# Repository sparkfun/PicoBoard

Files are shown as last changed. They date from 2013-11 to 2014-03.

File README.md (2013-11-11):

Picoboard
=========

[PicoBoard 
*PicoBoard (WIG-10311)*](https://www.sparkfun.com/products/10311)

The PicoBoard allows you to interface hardware sensors with the Scratch programming language.

Repository Contents
-------------------
* **/hardware** - All Eagle design files (.brd, .sch, .STL)
* **/firmware** - PicoBoard source code for an ATmega328.

License Information
-------------------
The contents released under [Creative Commons Share-alike 3.0](http://creativecommons.org/licenses/by-sa/3.0/).

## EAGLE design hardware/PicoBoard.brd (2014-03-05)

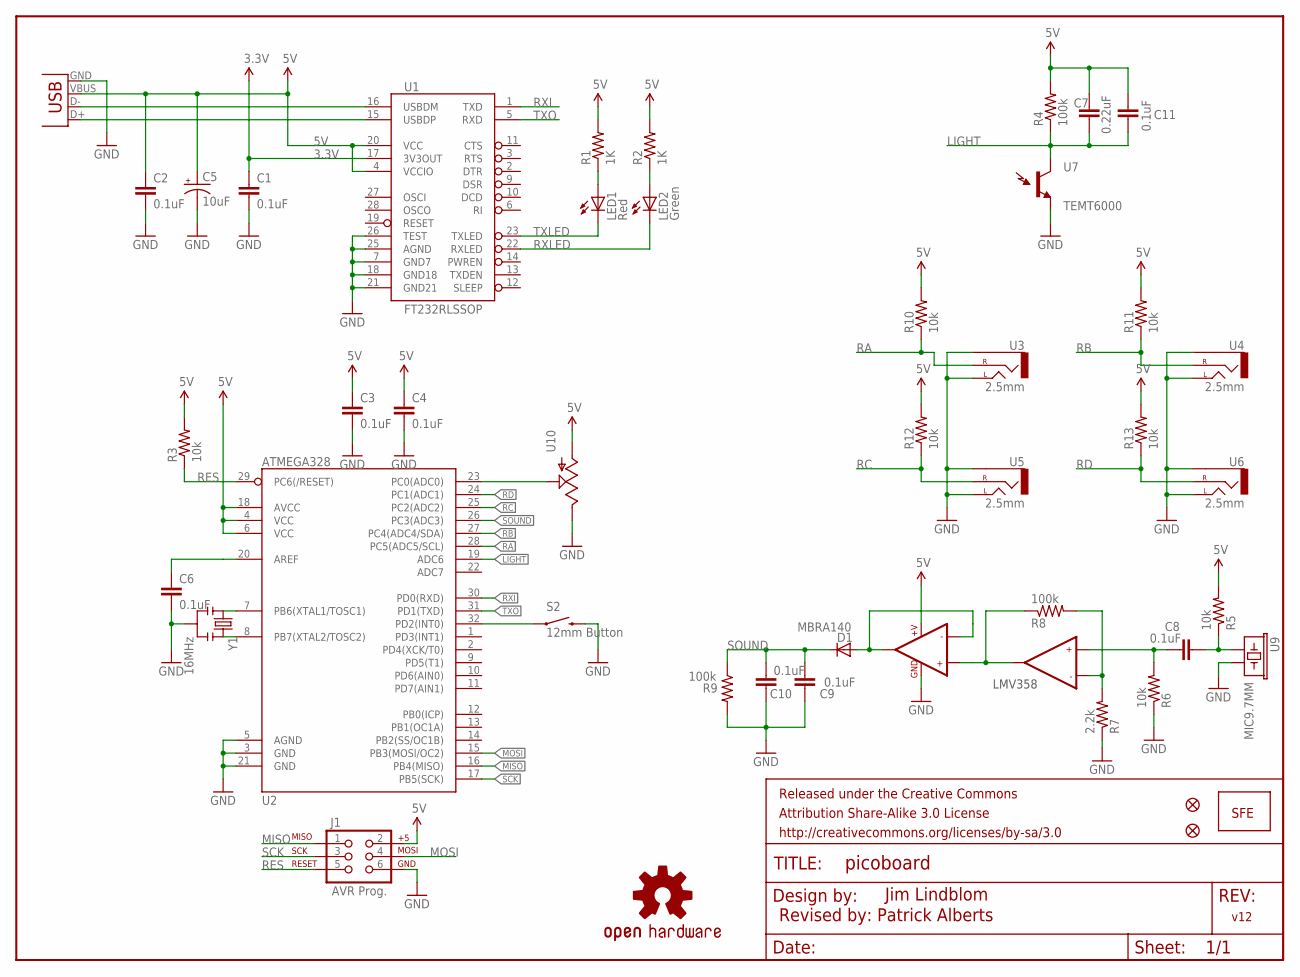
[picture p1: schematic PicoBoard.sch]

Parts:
C1, C2, C3, C4, C6, C8, C9, C10, C11: 0.1uF; 0603-CAP
C5: 10uF; EIA3216
C7: 0.22uF; 0603-CAP
D1: MBRA140; SMA-DIODE
FID1, FID2: FIDUCIAL1X2; FIDUCIAL-1X2
FRAME1: FRAME-LETTER; CREATIVE_COMMONS
J1: AVR Prog.; 2X3
JP1: LOGO-SFENEW; SFE-NEW-WEBLOGO
LED1: Red; LED-0603
LED2: Green; LED-0603
LOGO1: OSHW-LOGOL; OSHW-LOGO-L
R1, R2: 1K; 0603-RES
R3, R5, R6, R10, R11, R12, R13: 10k; 0603-RES
R4, R8, R9: 100k; 0603-RES
R7: 2.2k; 0603-RES
S2: 12mm Button; TACTILE-SMD-12MM
U1: FT232RLSSOP; SSOP28DB
U2: ATMEGA328; TQFP32-08
U3, U4, U5, U6: 2.5mm; STEREOJACK2.5MM
U7: TEMT6000; TEMT6000-SEN
U8: LMV358; SO08
U9: MIC9.7MM; MIC-9.7MM
U10: SLIDER60MM; SLIDER
X1: USBSMD; USB-MINIB
Y1: 16MHz; RESONATOR-SMD

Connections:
3.3V: C1.1, U1.17 (3V3OUT)
5V: C2.1, C3.1, C4.1, C5.A (+), C7.1, C11.1, J1.2, R1.2, R2.2, R3.2, R4.2, R5.2, R10.2, R11.2, R12.2, R13.2, U1.4 (VCCIO), U1.20 (VCC), U2.4 (VCC), U2.6 (VCC), U2.18 (AVCC), U8.8 (+V), U10.3 (A), X1.VBUS
GND: C1.2, C2.2, C3.2, C4.2, C5.C (-), C6.2, C9.1, C10.1, J1.6, R6.1, R7.1, R9.2, S2.3 (2), U1.7 (GND7), U1.18 (GND18), U1.21 (GND21), U1.25 (AGND), U1.26 (TEST), U2.3 (GND), U2.5 (AGND), U2.21 (GND), U3.1 (LEFT), U3.5 (SLEEVE), U4.1 (LEFT), U4.5 (SLEEVE), U5.1 (LEFT), U5.5 (SLEEVE), U6.1 (LEFT), U6.5 (SLEEVE), U7.EMITTER (E1), U8.4 (GND), U9.2, U10.1 (E), X1.GND, Y1.2
LIGHT: C7.2, C11.2, R4.1, U2.19 (ADC6), U7.COLLECTOR (C1)
MISO: J1.1, U2.16 (PB4(MISO))
MOSI: J1.4, U2.15 (PB3(MOSI/OC2))
unnamed: LED1.A, R1.1
unnamed: LED2.A, R2.1
unnamed: R7.2, R8.2, U8.6 (-IN2)
unnamed: U2.7 (PB6(XTAL1/TOSC1)), Y1.1
unnamed: U2.8 (PB7(XTAL2/TOSC2)), Y1.3
unnamed: C6.1, U2.20 (AREF)
unnamed: S2.1, U2.32 (PD2(INT0))
unnamed: C8.1, R5.1, U9.1
unnamed: U2.23 (PC0(ADC0)), U10.2A (S)
unnamed: C8.2, R6.2, U8.5 (+IN2)
unnamed: D1.A, U8.1 (OUT1), U8.2 (-IN1)
unnamed: R8.1, U8.3 (+IN1), U8.7 (OUT2)
RA: R10.1, U2.28 (PC5(ADC5/SCL)), U3.4 (RIGHT)
RB: R11.1, U2.27 (PC4(ADC4/SDA)), U4.4 (RIGHT)
RC: R12.1, U2.25 (PC2(ADC2)), U5.4 (RIGHT)
RD: R13.1, U2.24 (PC1(ADC1)), U6.4 (RIGHT)
RES: J1.5, R3.1, U2.29 (PC6(/RESET))
RXI: U1.1 (TXD), U2.30 (PD0(RXD))
RXLED: LED2.C, U1.22 (RXLED)
SCK: J1.3, U2.17 (PB5(SCK))
SOUND: C9.2, C10.2, D1.C, R9.1, U2.26 (PC3(ADC3))
TXLED: LED1.C, U1.23 (TXLED)
TXO: U1.5 (RXD), U2.31 (PD1(TXD))
USB_D+: U1.15 (USBDP), X1.D+
USB_D-: U1.16 (USBDM), X1.D-

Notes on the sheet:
LMV358
Jim Lindblom
Revised by: Patrick Alberts
v12

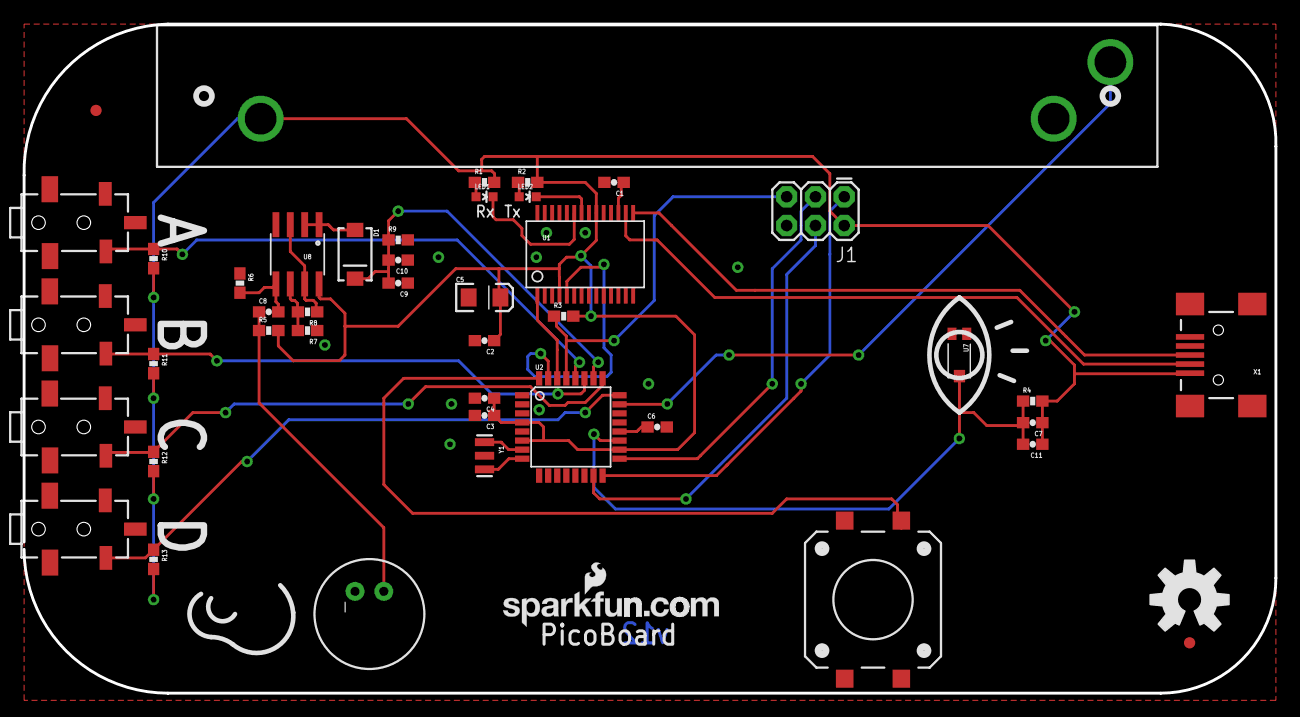
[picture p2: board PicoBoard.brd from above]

Board: 2 copper layers, 110.5 x 59.1 mm, 46 parts (0 on the bottom side), 31 nets.

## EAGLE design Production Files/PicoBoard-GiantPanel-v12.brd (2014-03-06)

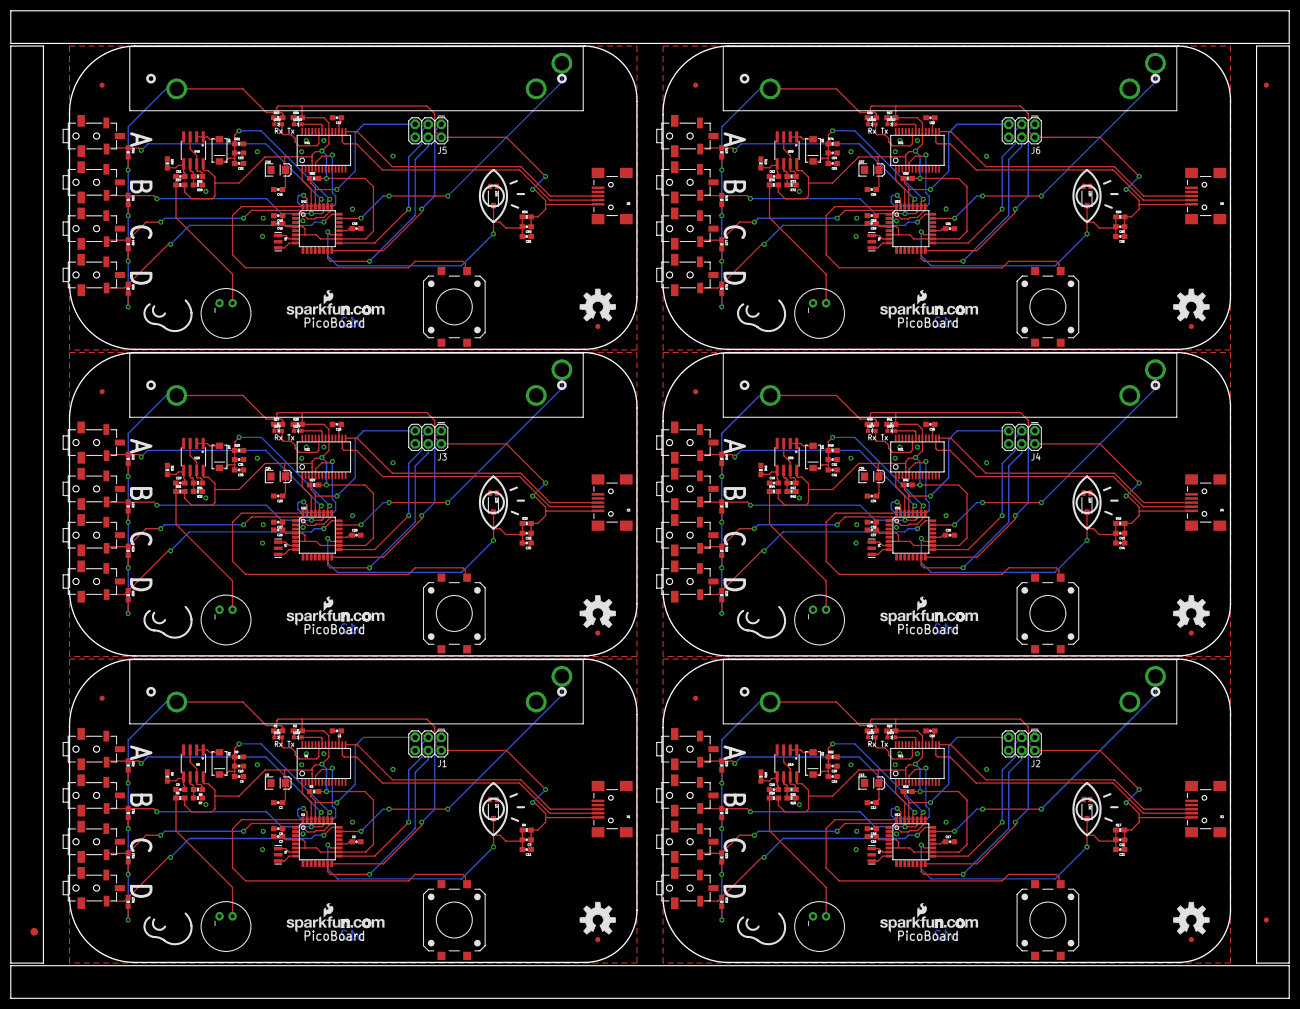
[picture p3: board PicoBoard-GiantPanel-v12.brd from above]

Board: 2 copper layers, 248.9 x 192.3 mm, 273 parts (0 on the bottom side), 186 nets.

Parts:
C1, C2, C3, C4, C6, C8, C9, C10, C11, C12, C14, C15, C16, C17, C18, C19, C20, C22, C23, C25, C26, C27, C28, C29, C30, C31, C33, C34, C36, C37, C38, C39, C40, C41, C42, C44, C45, C47, C48, C49, C50, C51, C52, C53, C55, C56, C58, C59, C60, C61, C62, C63, C64, C66: 0.1uF; 0603-CAP
C5, C13, C24, C35, C46, C57: 10uF; EIA3216
C7, C21, C32, C43, C54, C65: 0.22uF; 0603-CAP
D1, D2, D3, D4, D5, D6: MBRA140; SMA-DIODE
E$1: FIDUCIAL-1.5X3
E$2, E$4: FIDUCIAL-1X2
FID1, FID2, FID3, FID4, FID5, FID6, FID7, FID8, FID9, FID10, FID11, FID12: FIDUCIAL1X2; FIDUCIAL-1X2
J1, J2, J3, J4, J5, J6: AVR Prog.; 2X3
JP1, JP2, JP3, JP4, JP5, JP6: LOGO-SFENEW; SFE-NEW-WEBLOGO
LED1, LED3, LED5, LED7, LED9, LED11: Red; LED-0603
LED2, LED4, LED6, LED8, LED10, LED12: Green; LED-0603
LOGO1, LOGO2, LOGO3, LOGO4, LOGO5, LOGO6: OSHW-LOGOL; OSHW-LOGO-L
R1, R2, R14, R15, R27, R28, R40, R41, R53, R54, R66, R67: 1K; 0603-RES
R3, R5, R6, R10, R11, R12, R13, R16, R18, R19, R23, R24, R25, R26, R29, R31, R32, R36, R37, R38, R39, R42, R44, R45, R49, R50, R51, R52, R55, R57, R58, R62, R63, R64, R65, R68, R70, R71, R75, R76, R77, R78: 10k; 0603-RES
R4, R8, R9, R17, R21, R22, R30, R34, R35, R43, R47, R48, R56, R60, R61, R69, R73, R74: 100k; 0603-RES
R7, R20, R33, R46, R59, R72: 2.2k; 0603-RES
S1, S2, S3, S4, S5, S6: 12mm Button; TACTILE-SMD-12MM
U1, U11, U21, U31, U41, U51: FT232RLSSOP; SSOP28DB
U2, U12, U22, U32, U42, U52: ATMEGA328; TQFP32-08
U3, U4, U5, U6, U13, U14, U15, U16, U23, U24, U25, U26, U33, U34, U35, U36, U43, U44, U45, U46, U53, U54, U55, U56: 2.5mm; STEREOJACK2.5MM
U7, U17, U27, U37, U47, U57: TEMT6000; TEMT6000-SEN
U8, U19, U29, U39, U49, U59: LMV358; SO08
U9, U18, U28, U38, U48, U58: MIC9.7MM; MIC-9.7MM
U10, U20, U30, U40, U50, U60: SLIDER
X1, X2, X3, X4, X5, X6: USBSMD; USB-MINIB
Y1, Y2, Y3, Y4, Y5, Y6: 16MHz; RESONATOR-SMD

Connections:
3.3V: C1.1, U1.17
3.3V1: C14.1, U11.17
3.3V2: C25.1, U21.17
3.3V3: C36.1, U31.17
3.3V4: C47.1, U41.17
3.3V5: C58.1, U51.17
5V: C2.1, C3.1, C4.1, C5.A, C7.1, C11.1, J1.2, R1.2, R2.2, R3.2, R4.2, R5.2, R10.2, R11.2, R12.2, R13.2, U1.4, U1.20, U2.4, U2.6, U2.18, U8.8, U10.3, X1.VBUS
5V1: C12.1, C13.A, C15.1, C16.1, C21.1, C22.1, J2.2, R14.2, R15.2, R16.2, R17.2, R18.2, R23.2, R24.2, R25.2, R26.2, U11.4, U11.20, U12.4, U12.6, U12.18, U19.8, U20.3, X2.VBUS
5V2: C23.1, C24.A, C26.1, C27.1, C32.1, C33.1, J3.2, R27.2, R28.2, R29.2, R30.2, R31.2, R36.2, R37.2, R38.2, R39.2, U21.4, U21.20, U22.4, U22.6, U22.18, U29.8, U30.3, X3.VBUS
5V3: C34.1, C35.A, C37.1, C38.1, C43.1, C44.1, J4.2, R40.2, R41.2, R42.2, R43.2, R44.2, R49.2, R50.2, R51.2, R52.2, U31.4, U31.20, U32.4, U32.6, U32.18, U39.8, U40.3, X4.VBUS
5V4: C45.1, C46.A, C48.1, C49.1, C54.1, C55.1, J5.2, R53.2, R54.2, R55.2, R56.2, R57.2, R62.2, R63.2, R64.2, R65.2, U41.4, U41.20, U42.4, U42.6, U42.18, U49.8, U50.3, X5.VBUS
5V5: C56.1, C57.A, C59.1, C60.1, C65.1, C66.1, J6.2, R66.2, R67.2, R68.2, R69.2, R70.2, R75.2, R76.2, R77.2, R78.2, U51.4, U51.20, U52.4, U52.6, U52.18, U59.8, U60.3, X6.VBUS
GND: C1.2, C2.2, C3.2, C4.2, C5.C, C6.2, C9.1, C10.1, J1.6, R6.1, R7.1, R9.2, S2.3, U1.7, U1.18, U1.21, U1.25, U1.26, U2.3, U2.5, U2.21, U3.1, U3.5, U4.1, U4.5, U5.1, U5.5, U6.1, U6.5, U7.EMITTER, U8.4, U9.2, U10.1, X1.GND, Y1.2
GND1: C12.2, C13.C, C14.2, C15.2, C16.2, C17.2, C19.1, C20.1, J2.6, R19.1, R20.1, R22.2, S1.3, U11.7, U11.18, U11.21, U11.25, U11.26, U12.3, U12.5, U12.21, U13.1, U13.5, U14.1, U14.5, U15.1, U15.5, U16.1, U16.5, U17.EMITTER, U18.2, U19.4, U20.1, X2.GND, Y2.2
GND2: C23.2, C24.C, C25.2, C26.2, C27.2, C28.2, C30.1, C31.1, J3.6, R32.1, R33.1, R35.2, S3.3, U21.7, U21.18, U21.21, U21.25, U21.26, U22.3, U22.5, U22.21, U23.1, U23.5, U24.1, U24.5, U25.1, U25.5, U26.1, U26.5, U27.EMITTER, U28.2, U29.4, U30.1, X3.GND, Y3.2
GND3: C34.2, C35.C, C36.2, C37.2, C38.2, C39.2, C41.1, C42.1, J4.6, R45.1, R46.1, R48.2, S4.3, U31.7, U31.18, U31.21, U31.25, U31.26, U32.3, U32.5, U32.21, U33.1, U33.5, U34.1, U34.5, U35.1, U35.5, U36.1, U36.5, U37.EMITTER, U38.2, U39.4, U40.1, X4.GND, Y4.2
GND4: C45.2, C46.C, C47.2, C48.2, C49.2, C50.2, C52.1, C53.1, J5.6, R58.1, R59.1, R61.2, S5.3, U41.7, U41.18, U41.21, U41.25, U41.26, U42.3, U42.5, U42.21, U43.1, U43.5, U44.1, U44.5, U45.1, U45.5, U46.1, U46.5, U47.EMITTER, U48.2, U49.4, U50.1, X5.GND, Y5.2
GND5: C56.2, C57.C, C58.2, C59.2, C60.2, C61.2, C63.1, C64.1, J6.6, R71.1, R72.1, R74.2, S6.3, U51.7, U51.18, U51.21, U51.25, U51.26, U52.3, U52.5, U52.21, U53.1, U53.5, U54.1, U54.5, U55.1, U55.5, U56.1, U56.5, U57.EMITTER, U58.2, U59.4, U60.1, X6.GND, Y6.2
LIGHT: C7.2, C11.2, R4.1, U2.19, U7.COLLECTOR
LIGHT1: C21.2, C22.2, R17.1, U12.19, U17.COLLECTOR
LIGHT2: C32.2, C33.2, R30.1, U22.19, U27.COLLECTOR
LIGHT3: C43.2, C44.2, R43.1, U32.19, U37.COLLECTOR
LIGHT4: C54.2, C55.2, R56.1, U42.19, U47.COLLECTOR
LIGHT5: C65.2, C66.2, R69.1, U52.19, U57.COLLECTOR
MISO: J1.1, U2.16
MISO1: J2.1, U12.16
MISO2: J3.1, U22.16
MISO3: J4.1, U32.16
MISO4: J5.1, U42.16
MISO5: J6.1, U52.16
MOSI: J1.4, U2.15
MOSI1: J2.4, U12.15
MOSI2: J3.4, U22.15
MOSI3: J4.4, U32.15
MOSI4: J5.4, U42.15
MOSI5: J6.4, U52.15
unnamed: LED1.A, R1.1
unnamed: LED2.A, R2.1
unnamed: R7.2, R8.2, U8.6
unnamed: LED3.A, R14.1
unnamed: U2.7, Y1.1
unnamed: U2.8, Y1.3
unnamed: C6.1, U2.20
unnamed: S2.1, U2.32
unnamed: C8.1, R5.1, U9.1
unnamed: U2.23, U10.2A
unnamed: C8.2, R6.2, U8.5
unnamed: LED4.A, R15.1
unnamed: D1.A, U8.1, U8.2
unnamed: U12.7, Y2.1
unnamed: U12.8, Y2.3
unnamed: R8.1, U8.3, U8.7
unnamed: C17.1, U12.20
unnamed: S1.1, U12.32
unnamed: C18.1, R18.1, U18.1
unnamed: C18.2, R19.2, U19.5
unnamed: R20.2, R21.2, U19.6
unnamed: D2.A, U19.1, U19.2
unnamed: R21.1, U19.3, U19.7
unnamed: U12.23, U20.2A
unnamed: LED5.A, R27.1
unnamed: LED6.A, R28.1
unnamed: U22.7, Y3.1
unnamed: U22.8, Y3.3
unnamed: C28.1, U22.20
unnamed: S3.1, U22.32
unnamed: C29.1, R31.1, U28.1
unnamed: C29.2, R32.2, U29.5
unnamed: R33.2, R34.2, U29.6
unnamed: D3.A, U29.1, U29.2
unnamed: R34.1, U29.3, U29.7
unnamed: U22.23, U30.2A
unnamed: LED7.A, R40.1
unnamed: LED8.A, R41.1
unnamed: U32.7, Y4.1
unnamed: U32.8, Y4.3
unnamed: C39.1, U32.20
unnamed: S4.1, U32.32
unnamed: C40.1, R44.1, U38.1
unnamed: C40.2, R45.2, U39.5
unnamed: R46.2, R47.2, U39.6
unnamed: D4.A, U39.1, U39.2
unnamed: R47.1, U39.3, U39.7
unnamed: U32.23, U40.2A
unnamed: LED9.A, R53.1
unnamed: LED10.A, R54.1
unnamed: U42.7, Y5.1
unnamed: U42.8, Y5.3
unnamed: C50.1, U42.20
unnamed: S5.1, U42.32
unnamed: C51.1, R57.1, U48.1
unnamed: C51.2, R58.2, U49.5
unnamed: R59.2, R60.2, U49.6
unnamed: D5.A, U49.1, U49.2
unnamed: R60.1, U49.3, U49.7
unnamed: U42.23, U50.2A
unnamed: LED11.A, R66.1
unnamed: LED12.A, R67.1
unnamed: U52.7, Y6.1
unnamed: U52.8, Y6.3
unnamed: C61.1, U52.20
unnamed: S6.1, U52.32
unnamed: C62.1, R70.1, U58.1
unnamed: C62.2, R71.2, U59.5
unnamed: R72.2, R73.2, U59.6
unnamed: D6.A, U59.1, U59.2
unnamed: R73.1, U59.3, U59.7
unnamed: U52.23, U60.2A
RA: R10.1, U2.28, U3.4
RA1: R23.1, U12.28, U13.4
RA2: R36.1, U22.28, U23.4
RA3: R49.1, U32.28, U33.4
RA4: R62.1, U42.28, U43.4
RA5: R75.1, U52.28, U53.4
RB: R11.1, U2.27, U4.4
RB1: R24.1, U12.27, U14.4
RB2: R37.1, U22.27, U24.4
RB3: R50.1, U32.27, U34.4
RB4: R63.1, U42.27, U44.4
RB5: R76.1, U52.27, U54.4
RC: R12.1, U2.25, U5.4
RC1: R25.1, U12.25, U15.4
RC2: R38.1, U22.25, U25.4
RC3: R51.1, U32.25, U35.4
RC4: R64.1, U42.25, U45.4
RC5: R77.1, U52.25, U55.4
RD: R13.1, U2.24, U6.4
RD1: R26.1, U12.24, U16.4
RD2: R39.1, U22.24, U26.4
RD3: R52.1, U32.24, U36.4
RD4: R65.1, U42.24, U46.4
RD5: R78.1, U52.24, U56.4
RES: J1.5, R3.1, U2.29
RES1: J2.5, R16.1, U12.29
RES2: J3.5, R29.1, U22.29
RES3: J4.5, R42.1, U32.29
RES4: J5.5, R55.1, U42.29
RES5: J6.5, R68.1, U52.29
RXI: U1.1, U2.30
RXI1: U11.1, U12.30
RXI2: U21.1, U22.30
RXI3: U31.1, U32.30
RXI4: U41.1, U42.30
RXI5: U51.1, U52.30
RXLED: LED2.C, U1.22
RXLED1: LED4.C, U11.22
RXLED2: LED6.C, U21.22
RXLED3: LED8.C, U31.22
RXLED4: LED10.C, U41.22
RXLED5: LED12.C, U51.22
SCK: J1.3, U2.17
SCK1: J2.3, U12.17
SCK2: J3.3, U22.17
SCK3: J4.3, U32.17
SCK4: J5.3, U42.17
SCK5: J6.3, U52.17
SOUND: C9.2, C10.2, D1.C, R9.1, U2.26
SOUND1: C19.2, C20.2, D2.C, R22.1, U12.26
SOUND2: C30.2, C31.2, D3.C, R35.1, U22.26
SOUND3: C41.2, C42.2, D4.C, R48.1, U32.26
SOUND4: C52.2, C53.2, D5.C, R61.1, U42.26
SOUND5: C63.2, C64.2, D6.C, R74.1, U52.26
TXLED: LED1.C, U1.23
TXLED1: LED3.C, U11.23
TXLED2: LED5.C, U21.23
TXLED3: LED7.C, U31.23
TXLED4: LED9.C, U41.23
TXLED5: LED11.C, U51.23
TXO: U1.5, U2.31
TXO1: U11.5, U12.31
TXO2: U21.5, U22.31
TXO3: U31.5, U32.31
TXO4: U41.5, U42.31
TXO5: U51.5, U52.31
USB_D+: U1.15, X1.D+
USB_D+1: U11.15, X2.D+
USB_D+2: U21.15, X3.D+
USB_D+3: U31.15, X4.D+
USB_D+4: U41.15, X5.D+
USB_D+5: U51.15, X6.D+
USB_D-: U1.16, X1.D-
USB_D-1: U11.16, X2.D-
USB_D-2: U21.16, X3.D-
USB_D-3: U31.16, X4.D-
USB_D-4: U41.16, X5.D-
USB_D-5: U51.16, X6.D-

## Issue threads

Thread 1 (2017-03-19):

Scratch 2 Browser Support

michaelcaplan, 2017-03-19:
Hi There,

I'm looking for some advice.  My understanding is that with NPAPI being removed in Chrome an Firefox, options for using the Picoboard with any contemporary browser are currently nil (IE seems to not work for me either).  I gather that the only option is to use the AIR based Scratch 2 Offline Editor.

I'm trying to find the source for the original NPAPI plugins to see if I can hack together a solution that will work with contemporary firefox and chrome.

Any pointers?

Thanks,

Mike

thisandagain, 2017-03-19:
As per thread in https://github.com/LLK/scratch-flash/issues/1293

The Picoboard is supported in the online version of Scratch 2.0 via Chrome.

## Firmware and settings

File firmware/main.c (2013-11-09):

#include <string.h>
#include <stdlib.h>
#include <stdio.h>
#include <ctype.h>
#include <avr/io.h>
#include <avr/interrupt.h>
#include <avr/pgmspace.h>
#include <math.h>
#include "main.h"
#include "adc.h"

//================================================================
//Define Global Variables
//================================================================
char channel[8]={RD, RC, RB, BUTTON, RA, LIGHT, SOUND, SLIDER};

//================================================================


int main (void)
{	
	char request=0;
	unsigned int sensor_value=0;
	char data_packet[2]="";

	//Initialize AVR I/O, UART and Interrupts
    ioinit();
	//Initialize the ADC
	adcInit(1,0,7);	//AVcc reference, Right Adjusted, 125kHz clock
	
	printf("Start\n");
	while(1){

		request=uart_getchar();
		
		//If we get the value 1 on the serial port, send the sensor values.
		if(request==SCRATCH_DATA_REQUEST)
		{	
			//Send the ID packet
			buildScratchPacket(data_packet, 15, 0x04);
			sendScratchPacket(data_packet);
			
			//Read/Report channel 0 (Resistance-D)
			sensor_value=adcRead(RD);
			buildScratchPacket(data_packet, 0, sensor_value);
			sendScratchPacket(data_packet);
			
			//Read/Report Channel 1 (Resistance-C)
			sensor_value=adcRead(RC);
			buildScratchPacket(data_packet, 1, sensor_value);
			sendScratchPacket(data_packet);

			//Read/Report Channel 2 (Resistance-B)
			sensor_value=adcRead(RB);
			buildScratchPacket(data_packet, 2, sensor_value);
			sendScratchPacket(data_packet);			

			//Read/Report Channel 3 (Button)
			if(PIND & (1<<BUTTON))sensor_value=0xffff;
			else sensor_value=0;
			buildScratchPacket(data_packet, 3, sensor_value);
			sendScratchPacket(data_packet);	
			
			//Read/Report Channel 4(Resistance-A)
			sensor_value=adcRead(RA);
			buildScratchPacket(data_packet, 4, sensor_value);
			sendScratchPacket(data_packet);		

			//Read/Report Channel 5(LIGHT)
			sensor_value=adcRead(LIGHT);
			buildScratchPacket(data_packet, 5, sensor_value);
			sendScratchPacket(data_packet);	

			//Read/Report Channel 6(Sound)
			sensor_value=adcRead(SOUND);
			buildScratchPacket(data_packet, 6, sensor_value);
			sendScratchPacket(data_packet);			
			
			//Read/Report Channel 7(Slider)
			sensor_value=adcRead(SLIDER);
			sensor_value=abs(1023-sensor_value);
			buildScratchPacket(data_packet, 7, sensor_value);
			sendScratchPacket(data_packet);		
			
		}
	}
	
	
    return (0);
}

//==================================================
//Core functions
//==================================================
//Function Description: 
//Inputs: 
//Outputs:
//Return:      
//usage: 
void ioinit(void)
{
	//All of Port C are inputs
	DDRC &= ~((1<<SLIDER)|(1<<RD)|(1<<RC)|(1<<SOUND)|(1<<RB)|(1<<RA)|(1<<LIGHT));
	//Don't enable any pull-ups!

	//Initialize Port D
	DDRD &= ~((1<<BUTTON)|(1<<RXI));	//Button and Rx pin are inputs
	PORTD |= (1<<BUTTON)|(1<<RXI);		//Enable the pull-ups for the Rx and Button pins

	// USART Baud rate: 38400 (With 16 MHz Clock)
    UBRR0H = (MYUBRR >> 8) & 0x7F;	//Make sure highest bit(URSEL) is 0 indicating we are writing to UBRRH
	UBRR0L = MYUBRR;
    UCSR0A = (1<<U2X0);					//Double the UART Speed
	UCSR0B = (1<<RXEN0)|(1<<TXEN0);		//Enable Rx and Tx in UART
    UCSR0C = (1<<UCSZ00)|(1<<UCSZ01);		//8-Bit Characters
    stdout = &mystdout; //Required for printf init
	cli();
	
	// Init timer 2
	//Set Prescaler to 8. (Timer Frequency set to 16Mhz)
	//Used for delay routines
	TCCR2B = (1<<CS20); 	//Divde clock by 1 for 16 Mhz Timer 2 Frequency	
		
}


static int uart_putchar(char c, FILE *stream)
{
  if (c == '\n')
    uart_putchar('\r', stream);
  
  loop_until_bit_is_set(UCSR0A, UDRE0);
  UDR0 = c;
  return 0;
}

uint8_t uart_getchar(void)
{
    while( !(UCSR0A & (1<<RXC0)) );
	return(UDR0);
}

//General short delays
void delay_ms(uint16_t x)
{
    for (; x > 0 ; x--)
        delay_us(1000);
}

//General short delays
void delay_us(uint16_t x)
{    
    TIFR2 = (1<<TOV2); //Clear any interrupt flags on Timer2
    TCNT2= 240; //Setting counter to 239 will make it 16 ticks until TOV is set. .0625uS per click means 1 uS until TOV is set
    while(x>0){
		while( (TIFR2 & (1<<TOV2)) == 0);
		TIFR2 = (1<<TOV2); //Clear any interrupt flags on Timer2
		TCNT2=240;
		x--;
	}
} 

void buildScratchPacket(char * packet, int channel, int value){
	char upper_data=(char)((value&(unsigned int)0x380)>>7);	//Get the upper 3 bits of the value
	char lower_data=(char)(value&0x7f);	//Get the lower 7 bits of the value
	*packet++=((1<<7)|(channel<<3)|(upper_data));
	*packet++=lower_data;
}

void sendScratchPacket(char * packet){
	printf("%c", *packet++);
	delay_us(400);
	printf("%c", *packet++);
	delay_us(400);
}

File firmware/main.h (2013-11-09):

//*******************************************************
//					GPIO Definitions
#define SLIDER PINC0
#define RD	PINC1
#define RC	PINC2
#define SOUND	PINC3
#define RB	PINC4
#define RA	PINC5
#define LIGHT	PINC6

#define RXI	PIND0
#define TXO	PIND1
#define BUTTON PIND2


//*******************************************************
//						Macros
//*******************************************************
#define sbi(var, mask)   ((var) |= (uint8_t)(1 << mask))
#define cbi(var, mask)   ((var) &= (uint8_t)~(1 << mask))


//*******************************************************
//					General Definitions
//*******************************************************
#define MYUBRR 51	//Used to set the AVR Baud Rate TO 38400 (External 16MHz Oscillator)

#define SCRATCH_DATA_REQUEST	0x01
#define SCRATCH_FW_VER			0x04

//=======================================================
//					Function Definitions
//=======================================================
static int uart_putchar(char c, FILE *stream);
uint8_t uart_getchar(void);
static FILE mystdout = FDEV_SETUP_STREAM(uart_putchar, NULL, _FDEV_SETUP_WRITE);
void ioinit(void);
void delay_ms(uint16_t x);
void delay_us(uint16_t x);
void buildScratchPacket(char * packet, int channel, int value);
void sendScratchPacket(char * packet);

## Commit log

2013-09-23 Initial BRD/SCH file commit
    added board and schematic files with gitignore
    [PicoBoard.brd, PicoBoard.sch]
2013-10-11 0603 Changed, Schematic Changes
    Changed all caps and res to 0603 and re routed accordingly as well as
    added OSHW logo and cleaned up the schematice
    [PicoBoard.brd, PicoBoard.sch]
2013-11-09 Removing extra firmware files.
    [PicoBoard.brd, PicoBoard.sch]
2013-11-09 Removing dependencies
    [PicoBoard.brd, PicoBoard.sch]
2013-12-06 Stereo Jack 1:1 updated
    [PicoBoard.brd, PicoBoard.sch]
2013-12-16 Trace clean up
    [PicoBoard.brd]
2014-02-20 Re-Up
    The New REV somehow was lost, now it is not.
    [PicoBoard.brd]
2014-03-04 Re- Up
    95% of the orginal Rev files we're lost, updated the lost files.
    [PicoBoard.brd, PicoBoard.sch]
2014-03-05 Added board fiducials
    [PicoBoard.brd, PicoBoard.sch]
2014-03-06 Created giant panel v12
    [PicoBoard-GiantPanel-v12.brd]

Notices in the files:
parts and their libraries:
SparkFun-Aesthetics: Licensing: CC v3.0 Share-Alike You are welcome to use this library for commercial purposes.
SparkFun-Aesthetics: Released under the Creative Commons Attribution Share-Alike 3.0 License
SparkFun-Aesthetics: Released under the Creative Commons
